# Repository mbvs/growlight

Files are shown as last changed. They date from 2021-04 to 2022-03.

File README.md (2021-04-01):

# growlight
An Arduino growing lights timer

The growlight is a time switch based on the DS3231 Precision RTC.
It allows setting of current time, on-time and off-time with buttons, displays time on a 4 digit 7 segment display and switches the state of the connected lights based on set on- and off times.
It also features a 3-way toggle switch to manually turn on and off the lights or pass control to the timer.

## Hardware

* Arduino nano
* DS3231 Precision RTC Module
* 4 digit 7 segment display with TM1637 controller
* 4 buttons
* ON-OFF-ON SPDT toggle switch
* IRLZ34 Logic level N-Channel MOSFet
* various resistors and leds

## Software

Growlight is developed in Visual Studio Code with the PlatformIO Plugin. To compile and flash connect your board to the PC, edit the platformio.ini upload_port setting to your needs and issue
the platformIO build and upload commands.

## TODO
* switch fet and button confirm pins for easier rooting (perhaps shift more pins around)

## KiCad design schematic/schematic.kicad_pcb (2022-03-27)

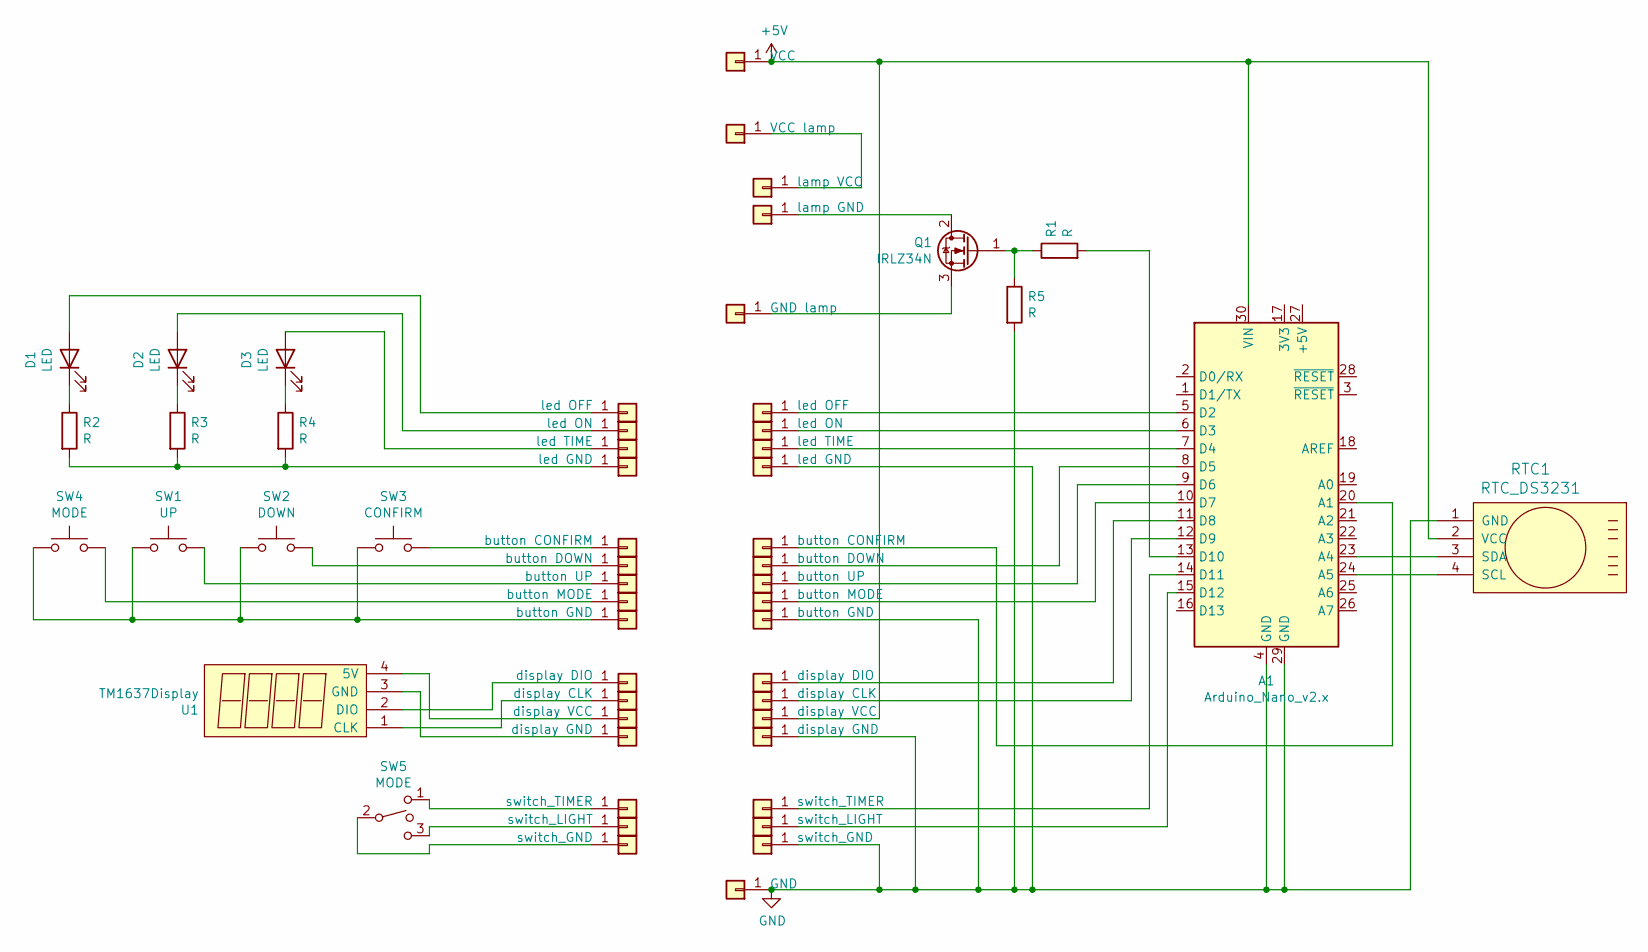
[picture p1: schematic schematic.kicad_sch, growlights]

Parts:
A1: Arduino_Nano_v2.x; Arduino_Nano
D1, D2, D3: LED; LED_D3.0mm
J1: lamp VCC; SolderWirePad_1x01_Drill0.8mm
J2: lamp GND; SolderWirePad_1x01_Drill0.8mm
J3, J16: led OFF; SolderWirePad_1x01_Drill0.8mm
J4, J17: led ON; SolderWirePad_1x01_Drill0.8mm
J5, J18: led TIME; SolderWirePad_1x01_Drill0.8mm
J6, J19: led GND; SolderWirePad_1x01_Drill0.8mm
J7, J20: button CONFIRM; SolderWirePad_1x01_Drill0.8mm
J8, J21: button DOWN; SolderWirePad_1x01_Drill0.8mm
J9, J22: button UP; SolderWirePad_1x01_Drill0.8mm
J10, J23: button MODE; SolderWirePad_1x01_Drill0.8mm
J11, J24: button GND; SolderWirePad_1x01_Drill0.8mm
J12, J25: display DIO; SolderWirePad_1x01_Drill0.8mm
J13, J26: display CLK; SolderWirePad_1x01_Drill0.8mm
J14, J27: display VCC; SolderWirePad_1x01_Drill0.8mm
J15, J28: display GND; SolderWirePad_1x01_Drill0.8mm
J29: VCC; SolderWirePad_1x01_Drill0.8mm
J30: VCC lamp; SolderWirePad_1x01_Drill0.8mm
J31: GND lamp; SolderWirePad_1x01_Drill0.8mm
J32: GND; SolderWirePad_1x01_Drill0.8mm
J33, J36: switch_TIMER; SolderWirePad_1x01_Drill0.8mm
J34, J37: switch_LIGHT; SolderWirePad_1x01_Drill0.8mm
J35, J38: switch_GND; SolderWirePad_1x01_Drill0.8mm
Q1: IRLZ34N; TO-220-3_Vertical
R1, R2, R3, R4, R5: R; R_Axial_DIN0207_L6.3mm_D2.5mm_P10.16mm_Horizontal
RTC1: RTC_DS3231
SW1: UP; SW_PUSH-12mm
SW2: DOWN; SW_PUSH-12mm
SW3: CONFIRM; SW_PUSH-12mm
SW4: MODE; SW_PUSH-12mm
SW5: MODE; SW_Toggle_Blue_wSlots
U1: TM1637Display; PinSocket_1x04_P2.54mm_Vertical

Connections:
+5V: A1.30 (VIN), J27.1, J29.1, RTC1.2 (VCC)
GND: A1.4 (GND), A1.29 (GND), J19.1, J24.1, J28.1, J32.1, J38.1, R5.2, RTC1.1 (GND)
unnamed: A1.5 (D2), J16.1
unnamed: A1.6 (D3), J17.1
unnamed: A1.7 (D4), J18.1
unnamed: A1.8 (D5), J21.1
unnamed: A1.9 (D6), J22.1
unnamed: A1.10 (D7), J23.1
unnamed: A1.11 (D8), J25.1
unnamed: A1.12 (D9), J26.1
unnamed: A1.13 (D10), R1.2
unnamed: A1.14 (D11), J36.1
unnamed: A1.15 (D12), J37.1
unnamed: A1.20 (A1), J20.1
unnamed: A1.23 (A4), RTC1.3 (SDA)
unnamed: A1.24 (A5), RTC1.4 (SCL)
unnamed: D1.1 (K), R2.1
unnamed: D1.2 (A), J3.1
unnamed: D2.1 (K), R3.1
unnamed: D2.2 (A), J4.1
unnamed: D3.1 (K), R4.1
unnamed: D3.2 (A), J5.1
unnamed: J1.1, J30.1
unnamed: J2.1, Q1.2 (D)
unnamed: J6.1, R2.2, R3.2, R4.2
unnamed: J7.1, SW3.2
unnamed: J8.1, SW2.2
unnamed: J9.1, SW1.2
unnamed: J10.1, SW4.2
unnamed: J11.1, SW1.1, SW2.1, SW3.1, SW4.1
unnamed: J12.1, U1.2 (DIO)
unnamed: J13.1, U1.1 (CLK)
unnamed: J14.1, U1.4 (5V)
unnamed: J15.1, U1.3 (GND)
unnamed: J31.1, Q1.3 (S)
unnamed: J33.1, SW5.1
unnamed: J34.1, SW5.3
unnamed: J35.1, SW5.2
unnamed: Q1.1 (G), R1.1, R5.1

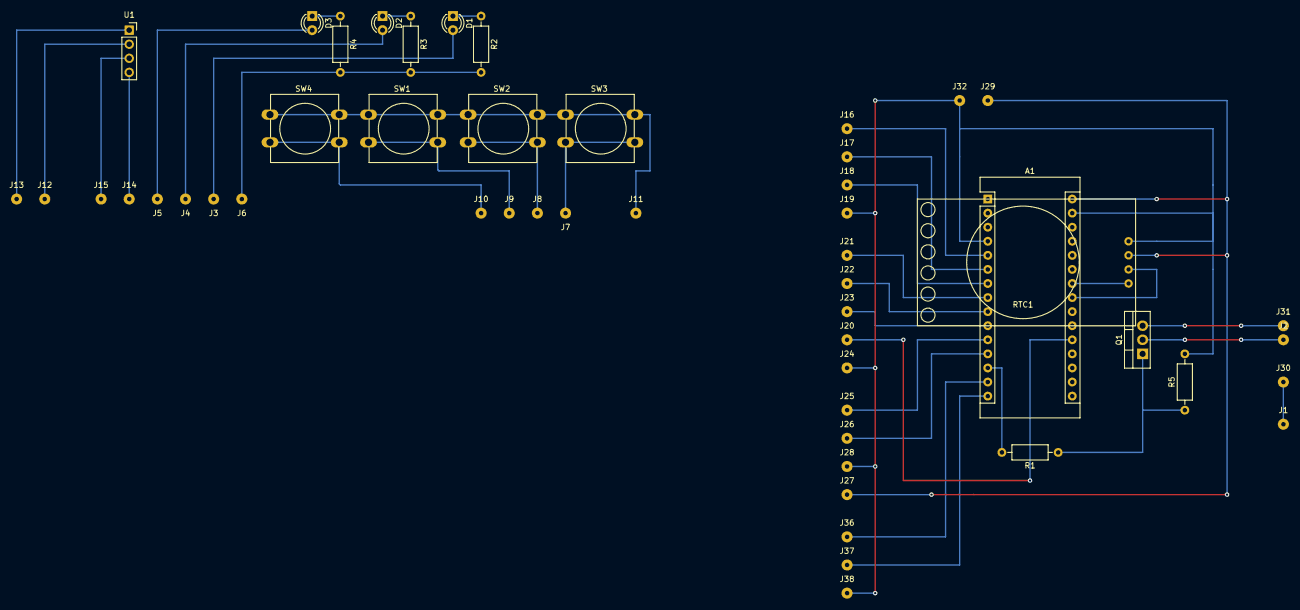
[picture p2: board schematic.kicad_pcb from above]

Board: 2 copper layers, 51 parts (0 on the bottom side), 36 nets.

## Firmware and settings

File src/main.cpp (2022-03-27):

#include <Arduino.h>
#include "OneButton.h"
#include "RTClib.h"

#include "defines.h"
#include "states.h"
#include "display.h"
#include "lights.h"

RTC_DS3231 rtc;

static OneButton stateButton(BUTTON_MODE, true);
static OneButton upButton(BUTTON_UP, true);
static OneButton downButton(BUTTON_DOWN, true);
static OneButton confirmButton(BUTTON_CONFIRM, true);

static void init_pins();

void setup()
{
  Serial.begin(9600);
  init_pins();
  init_states();
  init_display();

  if (!rtc.begin())
  {
    Serial.println("RTC ERROR");
    abort();
  }
 
  if (rtc.lostPower())
  {
    rtc.adjust(DateTime(F(__DATE__), F(__TIME__)));
  }

  // rtc.adjust(DateTime(F(__DATE__), F(__TIME__)));
  // DateTime now = rtc.now();
  // static TimeSpan step = TimeSpan(0, 0, 1, 0);
  // lightData->on = now + step;
  // lightData->off = now + step + step;
}

void loop()
{
  tick_states(lightData);
  tick_display(lightData);
  tick_lights(lightData);

  stateButton.tick();
  confirmButton.tick();
  downButton.tick();
  upButton.tick();
}

void init_pins()
{
  pinMode(LED_TIME, OUTPUT);
  pinMode(LED_ON, OUTPUT);
  pinMode(LED_OFF, OUTPUT);
  pinMode(FET, OUTPUT);

  pinMode(SWITCH_TIMER, INPUT_PULLUP);
  pinMode(SWITCH_LIGHT, INPUT_PULLUP);

  stateButton.attachClick(state);
  confirmButton.attachClick(confirm);

  upButton.attachClick(up);
  upButton.attachDuringLongPress(up);

  downButton.attachClick(down);
  downButton.attachDuringLongPress(down);
}

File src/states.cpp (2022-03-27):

#include <EEPROM.h>
#include "RTClib.h"
#include "states.h"
#include "defines.h"


/**
 * states.cpp
 * 
 * Handles global states depending on button-pushes and status of toggle switch
 */

extern RTC_DS3231 rtc;

static const int IDLE_LONG = 5000;                       // fallback delay when in on or off state
static const int IDLE_SHORT = 1000;                      // fallback delay after a blink
static const TimeSpan step_big = TimeSpan(0, 0, 5, 0);   // 5 min - step for on or off times
static const TimeSpan step_small = TimeSpan(0, 0, 1, 0); // 1 min - step for time

static unsigned long max_idle; // fallback delay (holds IDLE_LONG or IDLE_SHORT)
static unsigned long then;     // timing

static LightData initial;        // declaration for lightData pointer
LightData *lightData = &initial; // declaration of lightData pointer

static void tick_mode();

/**
 * Initializes the state with starting values
 */
void init_states()
{
    initial = {
        .mode = MODE_OFF,
        .state = STATE_TIME,
        .time = rtc.now(),
        .on = DateTime(1, 1, 1, int(EEPROM.read(0)), int(EEPROM.read(1)), 0),
        .off = DateTime(1, 1, 1, int(EEPROM.read(2)), int(EEPROM.read(3)), 0),
        .blink = false,
        .dirty = true
        };
}

/**
 * Ticks the states in every loop
 */
void tick_states(LightData *store)
{
    tick_mode();

    // fallback-routine when nothing happens in on or off state
    if (store->state != STATE_TIME && millis() - then > max_idle)
    {
        store->dirty = true;
        store->state = STATE_TIME;
        store->on = DateTime(1, 1, 1, int(EEPROM.read(0)), int(EEPROM.read(1)), 0);
        store->off = DateTime(1, 1, 1, int(EEPROM.read(2)), int(EEPROM.read(3)), 0);
        Serial.println("falling back to state STATE_TIME");
    }
}

/**
 * Resets the idle interval after push on up or down
 */
void idleReset(int idle_time)
{
    max_idle = idle_time;
    then = millis();
}

/**
 * Writes actual on/off times to eeprom after confirm push
 * (when something was actually changed)
 */
bool writeEEPROM(int add_hour, int add_minute, int hour, int minute)
{
    bool written = false;
    if (int(EEPROM.read(add_hour)) != hour)
    {
        EEPROM.write(add_hour, byte(hour));
        written = true;
    }
    if (int(EEPROM.read(add_minute)) != minute)
    {
        EEPROM.write(add_minute, byte(minute));
        written = true;
    }

    return written;
}

/**
 * Checks status of toggle switch and sets mode
 */
void tick_mode()
{
    if (digitalRead(SWITCH_LIGHT) == LOW && lightData->mode != MODE_LIGHTS)
    {
        lightData->mode = MODE_LIGHTS;
        Serial.println("switching mode to MODE_LIGHTS");
    }
    else if (digitalRead(SWITCH_TIMER) == LOW && lightData->mode != MODE_TIMER)
    {
        lightData->mode = MODE_TIMER;
        Serial.println("switching mode to MODE_TIMER");
    }
    else if (digitalRead(SWITCH_TIMER) != LOW && digitalRead(SWITCH_LIGHT) != LOW && lightData->mode != MODE_OFF)
    {
        lightData->mode = MODE_OFF;
        Serial.println("switching mode to MODE_OFF");
    }
}


/**
 * StateButton was pushed
 */
void state()
{
    Serial.println("state button pressed");
    lightData->dirty = true;
    idleReset(IDLE_LONG);

    if (lightData->state == STATE_TIME)
    {
        lightData->state = STATE_ON;
        Serial.println("switching state to STATE_ON");
    }
    else if (lightData->state == STATE_ON)
    {
        lightData->state = STATE_OFF;
        Serial.println("switching state to STATE_OFF");
    }
    else if (lightData->state == STATE_OFF || lightData->state == STATE_SET_TIME)
    {
        lightData->state = STATE_TIME;
        Serial.println("switching state to STATE_TIME");
    }
}

/**
 * ConfirmButton was pushed
 */
void confirm()
{
    Serial.println("confirm button pressed");
    idleReset(IDLE_SHORT);
    lightData->blink = true;
    lightData->dirty = true;

    if (lightData->state == STATE_ON)
    {
        writeEEPROM(0, 1, lightData->on.hour(), lightData->on.minute());
        Serial.print("setting ON time to ");
        Serial.println(lightData->on.hour()*100 + lightData->on.minute());
    }
    else if (lightData->state == STATE_OFF)
    {
        writeEEPROM(2, 3, lightData->off.hour(), lightData->off.minute());
        Serial.print("setting OFF time to ");
        Serial.println(lightData->off.hour()*100 + lightData->off.minute());
    }
    else if (lightData->state == STATE_SET_TIME)
    {
        rtc.adjust(DateTime(lightData->time));
        Serial.print("setting time to ");
        Serial.println(lightData->time.hour()*100 + lightData->time.minute());
    }
}

/**
 * DownButton was pushed
 */
void down()
{
    Serial.println("down button pressed");
    lightData->dirty = true;
    idleReset(IDLE_LONG);

    if (lightData->state == STATE_TIME)
    {
        lightData->time = rtc.now() - step_small;
        lightData->state = STATE_SET_TIME;
        Serial.println("switching state to STATE_SET_TIME");
    }
    else if (lightData->state == STATE_SET_TIME)
    {
        lightData->time = lightData->time - step_small;
    }
    else if (lightData->state == STATE_ON)
    {
        lightData->on = lightData->on - step_big;
    }
    else if (lightData->state == STATE_OFF)
    {
        lightData->off = lightData->off - step_big;
    }
}

/**
 * UpButton was pushed
 */
void up()
{
    Serial.println("up button pressed");
    lightData->dirty = true;
    idleReset(IDLE_LONG);

    if (lightData->state == STATE_TIME)
    {
        lightData->time = rtc.now() + step_small;
        lightData->state = STATE_SET_TIME;
    }
    else if (lightData->state == STATE_SET_TIME)
    {
        lightData->time = lightData->time + step_small;
    }
    else if (lightData->state == STATE_ON)
    {
        lightData->on = lightData->on + step_big;
    }
    else if (lightData->state == STATE_OFF)
    {
        lightData->off = lightData->off + step_big;
    }
}

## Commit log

2021-03-10 refactor light switching algorithm
2021-03-12 add KiCad schematic
    [schematic.kicad_pcb, schematic.sch]
2021-03-15 add mode toggle switch
2021-03-15 setup confirm button
2021-03-16 implement set button
2021-03-20 fix counting of dimm values
    [lights.cpp]
2021-03-20 draw schematics
    [schematic.kicad_pcb, schematic.sch]
2021-03-25 update board
    [schematic.kicad_pcb, schematic.sch]
2021-04-01 make arduino part of pcb
    [schematic.kicad_pcb, schematic.sch]
2022-03-27 update schematic to KiCad 6
    [schematic.kicad_pcb, schematic.kicad_sch, schematic.sch]
